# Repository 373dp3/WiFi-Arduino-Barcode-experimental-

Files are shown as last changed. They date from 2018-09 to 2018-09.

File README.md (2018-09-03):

# 概要
WiFiマイコン(ESP-WROOM-02)にバーコードリーダー、テンキー、1602液晶を組み合わせたミニマルなシンクライアントです。
生産工程などで大規模導入する場合、パソコン自体のコスト(初期、電気代等のランニングも無視できません。
WiFi Arduino Barcodeでは従来の1/10のコストでの生産工程進捗管理を目指します。

## システム構成(全体)
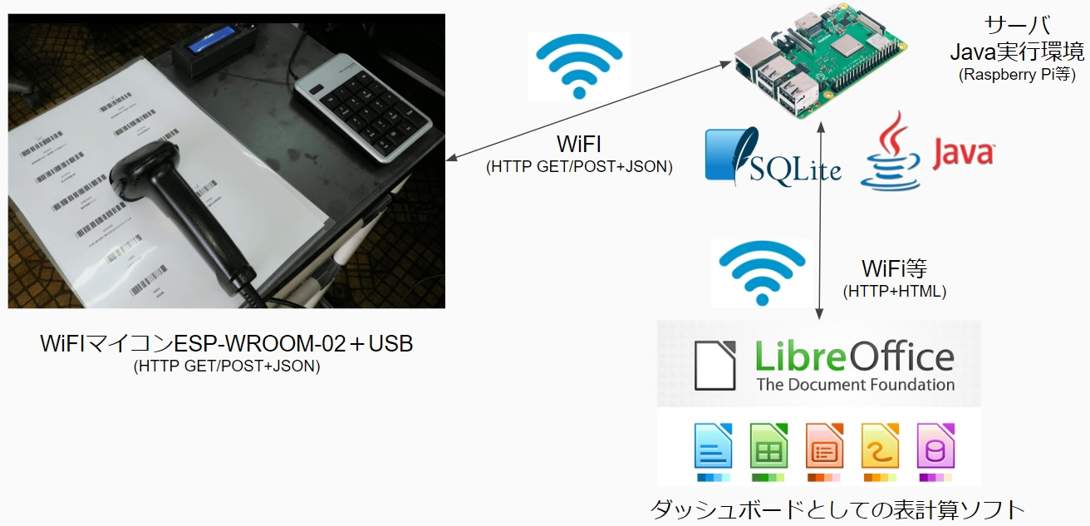
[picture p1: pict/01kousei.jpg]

<ul>
<li>WiFi Arduino Barcode(HTTP GET/POST & JSON)</li>
<li>ローカルサーバ / Javaを実行可能な環境 / (HTTP経由でのtable参照)</li>
<li>表示用表計算ソフト(LibreOffice等)</li>
</ul>

## ハードウェア構成(クライアント)
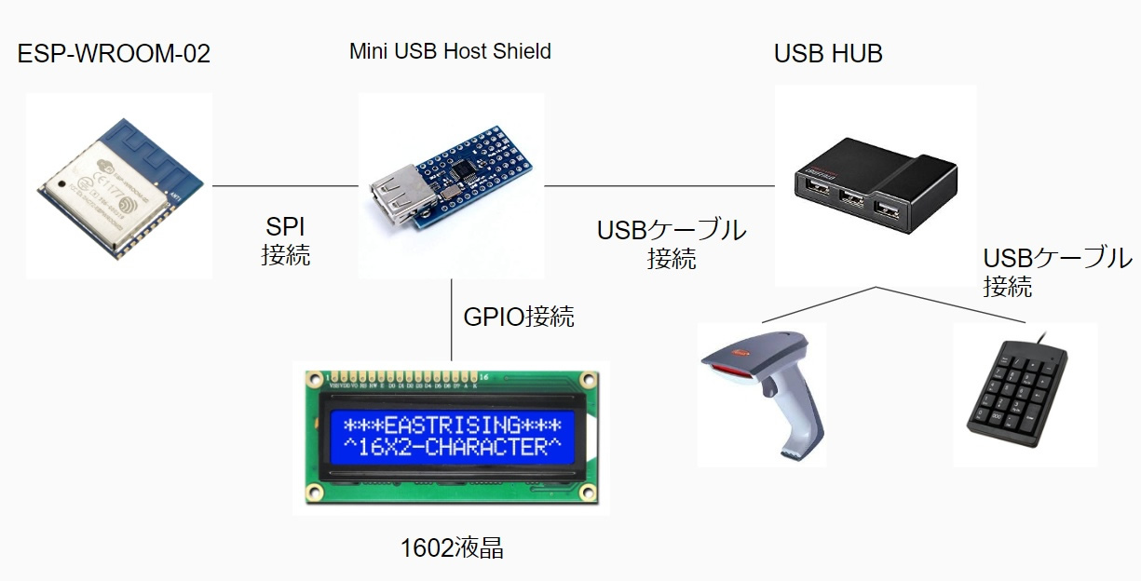
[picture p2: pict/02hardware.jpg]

<ul>
<li>ESP-WROOM-02</li>
<li>Mini USB Host Shield(SPI接続)</li>
<li>バーコードリーダー(USB接続)</li>
<li>テンキー(USB接続)</li>
<li>USBハブ</li>
<li>LCD1602(Mini USB Host Shield経由でのGPIO接続)</li>
</ul>

## フォルダ構成
<table>
  <tr>
    <td>client </td>
    <td>ESP-WROOM-02と<a href="https://amzn.to/2LSpzPm">Mini USB Host Shield</a>を用いたバーコードリーダー端末に関する情報
 </td>
  </tr>
  <tr>
    <td>client/eagle </td>
    <td>基板設計ソフト EAGLE用のファイル</td>
  </tr>
  <tr>
    <td>LocalBarcodeServer </td>
    <td>ローカルサーバ用ファイル一式 </td>
  </tr>
  <tr>
    <td>LocalBarcodeServer/binary </td>
    <td>実行に必要なファイルのみ </td>
  </tr>
</table>

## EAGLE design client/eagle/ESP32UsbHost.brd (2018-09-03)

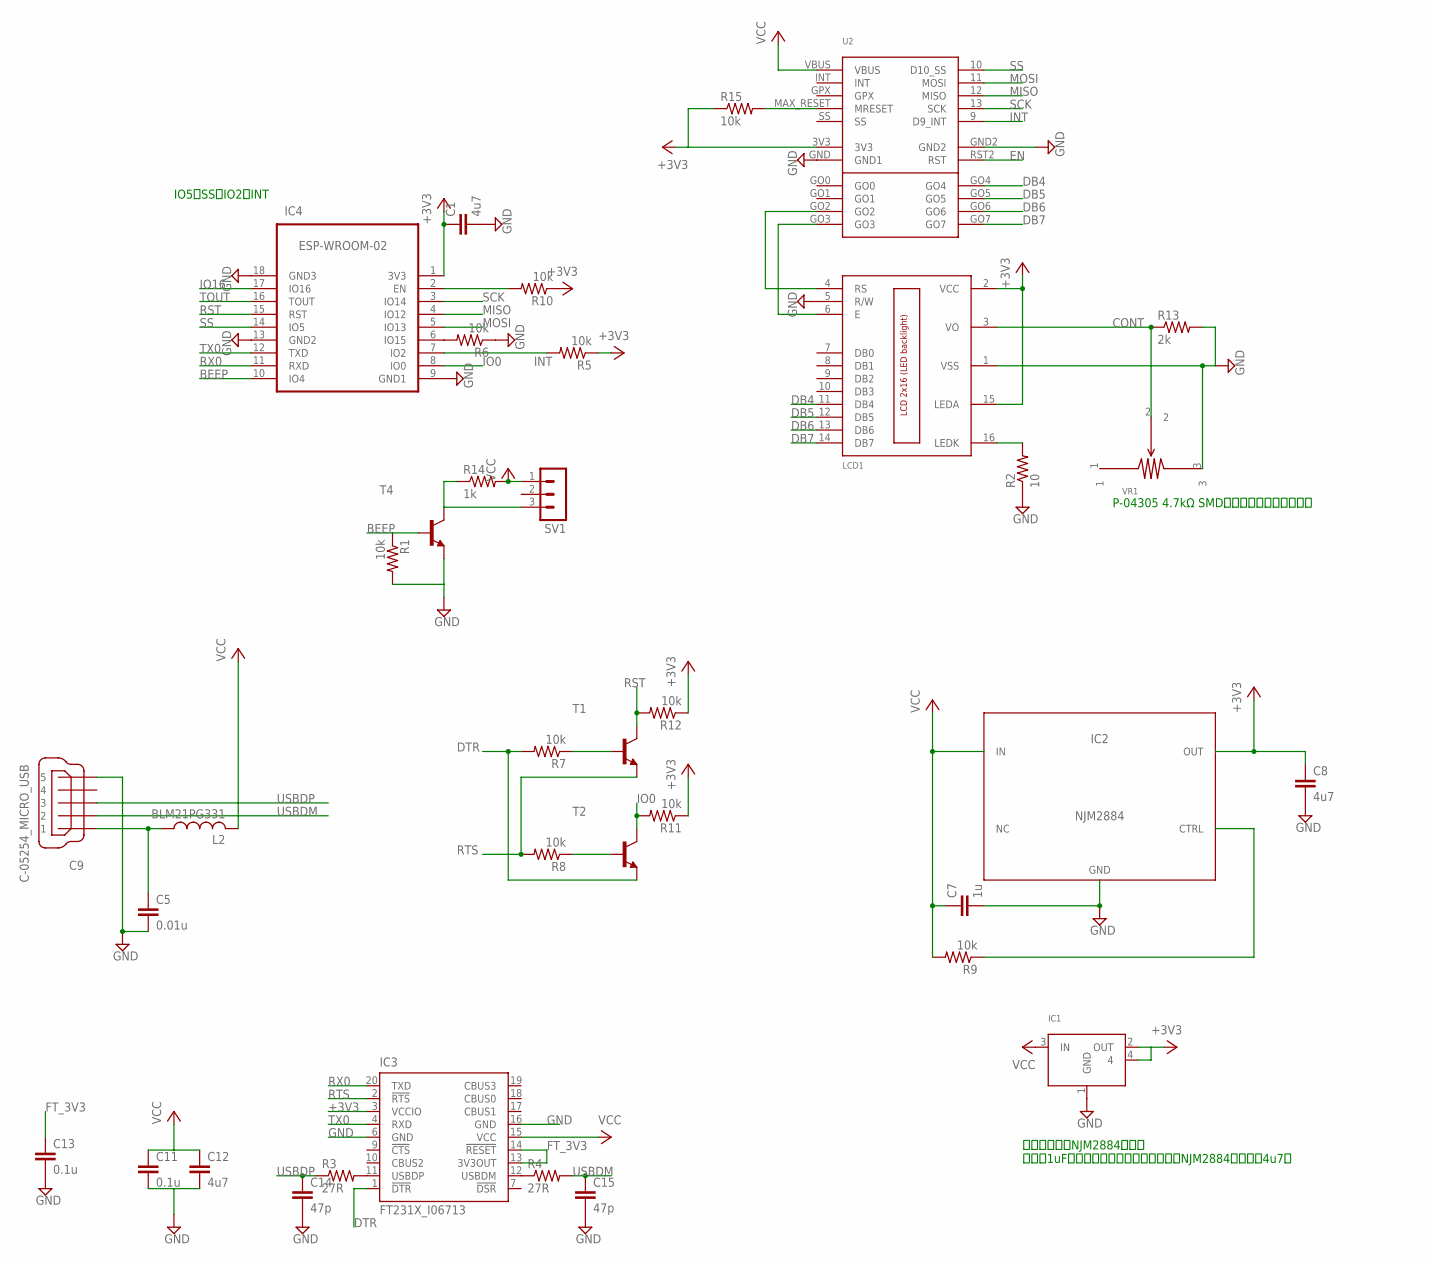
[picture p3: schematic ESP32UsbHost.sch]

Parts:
C1, C8, C12: 4u7; C0603
C5: 0.01u; C0603
C7: 1u; C0603
C9: C-05254_MICRO_USB
C11, C13: 0.1u; C0603
C14, C15: 47p; C0603
IC1: I-12635_ADP3338AKCZ; SOT223
IC2: NJM2884; SOT89-5
IC3: FT231X_I06713; SSOP20(2)
IC4: ESP-WROOM-02; FRONT-FACE_HANDSOLDER
L2: BLM21PG331; L2012C
LCD1: LCD_2X16CONN_ONLY; HY-1602F_2
R1, R5, R6, R7, R8, R9, R10, R11, R12, R15: 10k; R0603
R2: 10; R0603
R3, R4: 27R; R0603
R13: 2k; R0603
R14: 1k; R0603
SV1: MA03-1
T1, T2, T4: BC808-NPN-SOT23-BEC; SOT23-BEC
U2: USB_HOST_MINI
VR1: P-04305_PVZ3_VR_POTENTION_METER; VR_POTENTION_METER

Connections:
+3V3: C1.1, C8.1, IC1.2 (OUT), IC1.4, IC2.4 (OUT), IC3.3 (VCCIO), IC4.1 (3V3), LCD1.2 (VCC), LCD1.15 (LEDA), R5.1, R10.1, R11.1, R12.1, R15.1, U2.3V3
BEEP: IC4.10 (IO4), R1.1, T4.B
CONT: LCD1.3 (VO), R13.1, VR1.2
DB4: LCD1.11 (DB4), U2.GO4
DB5: LCD1.12 (DB5), U2.GO5
DB6: LCD1.13 (DB6), U2.GO6
DB7: LCD1.14 (DB7), U2.GO7
DTR: IC3.1 (!DTR), R7.2, T2.E
EN: U2.RST2 (RST)
FT_3V3: C13.1, IC3.13 (3V3OUT), IC3.14 (!RESET)
GND: C1.2, C5.2, C7.2, C8.2, C9.5, C11.2, C12.2, C13.2, C14.2, C15.2, IC1.1 (GND), IC2.2 (GND), IC3.6 (GND), IC3.16 (GND), IC4.9 (GND1), IC4.13 (GND2), IC4.18 (GND3), LCD1.1 (VSS), LCD1.5 (R/W), R1.2, R2.1, R6.1, R13.2, T4.E, U2.GND (GND1), U2.GND2, VR1.3
INT: IC4.7 (IO2), R5.2, U2.9 (D9_INT)
IO0: IC4.8 (IO0), R11.2, T2.C
IO16: IC4.17 (IO16)
MISO: IC4.4 (IO12), U2.12 (MISO)
MOSI: IC4.5 (IO13), U2.11 (MOSI)
unnamed: IC4.6 (IO15), R6.2
unnamed: LCD1.6 (E), U2.GO3
unnamed: LCD1.4 (RS), U2.GO2
unnamed: LCD1.16 (LEDK), R2.2
unnamed: IC3.12 (USBDM), R4.1
unnamed: IC3.11 (USBDP), R3.2
unnamed: IC4.2 (EN), R10.2
unnamed: R14.1, SV1.3, T4.C
unnamed: R15.2, U2.MAX_RESET (MRESET)
unnamed: R7.1, T1.B
unnamed: C5.1, C9.1, L2.1
unnamed: R8.1, T2.B
unnamed: IC2.1 (CTRL), R9.1
RST: IC4.15 (RST), R12.2, T1.C
RTS: IC3.2 (!RTS), R8.2, T1.E
RX0: IC3.20 (TXD), IC4.11 (RXD)
SCK: IC4.3 (IO14), U2.13 (SCK)
SS: IC4.14 (IO5), U2.10 (D10_SS)
TOUT: IC4.16 (TOUT)
TX0: IC3.4 (RXD), IC4.12 (TXD)
USBDM: C9.2, C15.1, R4.2
USBDP: C9.3, C14.1, R3.1
VCC: C7.1, C11.1, C12.1, IC1.3 (IN), IC2.5 (IN), IC3.15 (VCC), L2.2, R9.2, R14.2, SV1.1, U2.VBUS

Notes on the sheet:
コンデンサはNJM2884と共用 出力に1uF以上。温度安定性を考えれば、NJM2884と同じく4u7。
IO5がSS、IO2がINT
P-04305 4.7kΩ SMDトリマポテンショメータ

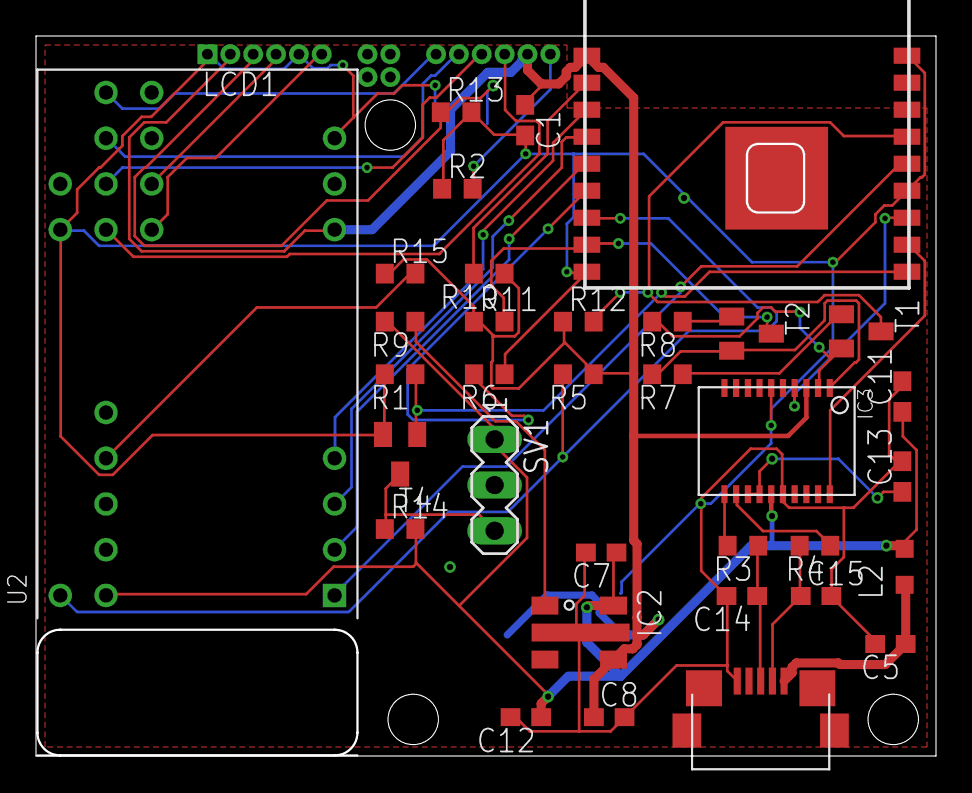
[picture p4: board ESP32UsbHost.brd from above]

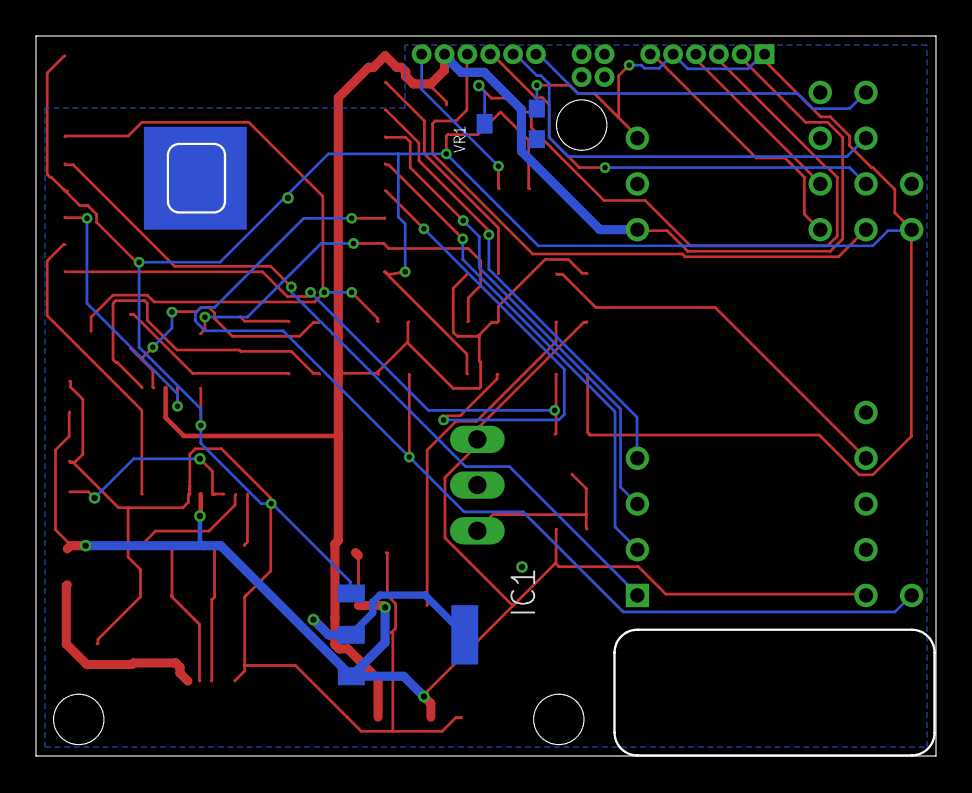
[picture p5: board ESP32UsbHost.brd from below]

Board: 2 copper layers, 50.0 x 40.0 mm, 37 parts (2 on the bottom side), 36 nets.

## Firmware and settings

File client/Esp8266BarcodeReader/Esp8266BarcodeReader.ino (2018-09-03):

/*
Name:		Esp8266BarcodeReader.ino
Created:	2018/03/06 8:42:33
Author:	min
*/

//#define DP3_ESP32

#include "Config.h"
#include "NetworkManager.h"
#include "TableViewManager.h"
#include "NormalOperationManager.h"
#include "CommonController.h"

#include <FS.h>

#include "HIDSelector.h"
#include "TxManager.h"
#include "FTDIAsync.h"
#include <cdcftdi.h>
#include <usbhub.h>
#include "LcdManager.h"

#ifdef dobogusinclude
#include <spi4teensy3.h>
#endif
#include <SPI.h>


NetworkManager net = NetworkManager();

StaticJsonBuffer<JSON_BUFFER_SIZE> JSONBuffer;



USB			Usb;
USBHub		Hub(&Usb);

// USB Hub and keyboard
USBHub     Hub2(&Usb);
HIDSelector    hid1(&Usb);
HIDSelector    hid2(&Usb);
HIDSelector    hid3(&Usb);
Max_LCD lcd(&Usb);
LcdManager scr(&lcd, BEEP_PIN);
HIDBoot<USB_HID_PROTOCOL_KEYBOARD>    HidKeyboard(&Usb);
CommonController *cc = NULL;
NormalOperationManager normOpMgr = NormalOperationManager();
TableViewWrapper * pTableOpMgr = NULL;

void updateConfig() {
	unsigned long timeout = millis() + 200;
	char* chBuf = (char*)malloc(JSON_POST_BUFFER_SIZE);
	char* chBuf2 = (char*)malloc(JSON_POST_BUFFER_SIZE);
	memset(chBuf, 0, JSON_POST_BUFFER_SIZE);
	memset(chBuf2, 0, JSON_POST_BUFFER_SIZE);
	int size = Serial.readBytesUntil(0x0d, chBuf, JSON_POST_BUFFER_SIZE);
	bool isReboot = false;
	if (size > 10) {
		memcpy(chBuf2, chBuf, JSON_POST_BUFFER_SIZE);
		JSONBuffer.clear();
		Serial.print("RECV:"); Serial.println(chBuf);
		JsonObject& parsed = JSONBuffer.parseObject(chBuf);
		if (parsed.success()) {
			if (parsed.containsKey("cmd")) {
				if (strcmp("format", parsed["cmd"].asString()) == 0) {
					Serial.println("Start SPIFFS format");
					SPIFFS.begin();
					SPIFFS.format();
					SPIFFS.end();
					Serial.println("format done.");
					Serial.println(F("{\"status\": 200, \"msg\": \"format done\"}"));
				}
				if (strcmp("ping", parsed["cmd"].asString()) == 0) {
					Serial.println(F("{\"status\": 200, \"msg\": \"pong\"}"));
				}
				if (strcmp("w", parsed["cmd"].asString()) == 0) {
					SPIFFS.begin();
					File file = SPIFFS.open(CONFIG_FILE, "w");
					if (file == NULL) {
						Serial.print("SPIFFS format");
						SPIFFS.format();
						Serial.println(" done.");
						file = SPIFFS.open(CONFIG_FILE, "w");
						if (file == NULL) {
							Serial.println(F("{\"status\": 500, \"msg\": \"Cannot format SPIFFS\"}"));
							return;
						}
					}
					file.print(chBuf2);
					file.close();

					Serial.println(F("{\"status\": 200, \"msg\": \"write done\"}"));
					isReboot = true;
				}
			}
		}
	}
	free(chBuf);
	free(chBuf2);
	if (isReboot) {
		delay(1000);
		ESP.reset();
	}
}


// the setup function runs once when you press reset or power the board
void setup() {
	Serial.begin(38400);
	Serial.setTimeout(200);
	Serial.println(F("Start"));


	if (Usb.Init() == -1)
		Serial.println(F("OSC did not start."));

	net.setupWiFi(&lcd);


	UsbDEBUGlvl = 0xff;
	Serial.println(F("USB host start"));
	hid1.init(); hid2.init(); hid3.init();

#ifndef DP3_ESP32
	//事前にロードしなくては音がでない場合がある為
	pinMode(BEEP_PWM_PIN, OUTPUT);
	analogWriteFreq(4000);
	analogWrite(BEEP_PWM_PIN, 128);
	delay(50);
	analogWrite(BEEP_PWM_PIN, 0);
	pinMode(BEEP_PWM_PIN, INPUT);
#endif


	//*/
	//入力フックの設定
	HIDSelector::setCommonController(&normOpMgr);

	lcd.clear();
	lcd.print("Connect USB ...");
	char chWait[] = { '-','\\', '|', '/' ,'-','\\','|','/' };
	while (1) {
		Usb.Task();
		if (Usb.getUsbTaskState() == USB_STATE_RUNNING) {
			lcd.clear();
			lcd.print("USB detected.");
			unsigned long limitMs = millis() + 3000;
			lcd.setCursor(0, 1);
			lcd.print("wait 3 sec.");
			for (int i = 0; i < 30; i++) {
				if (millis() > limitMs) { break; }
				delay(100);
				lcd.setCursor(12, 1);
				lcd.print(chWait[i % sizeof(chWait)]);
				Usb.Task();
			}
			break;
		}
		else {
			delay(500);
		}
	}

	//初期アクセス
	normOpMgr.post();
}



// the loop function runs over and over again until power down or reset
void loop() {
	Usb.Task();

	if (Serial.available() > 0) {
		updateConfig();
	}

	if (Usb.getUsbTaskState() != USB_STATE_RUNNING) { return; }

	scr.Task();
}

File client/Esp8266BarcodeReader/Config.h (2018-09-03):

// Config.h

#ifndef _CONFIG_h
#define _CONFIG_h

#if defined(ARDUINO) && ARDUINO >= 100
	#include "arduino.h"
#else
	#include "WProgram.h"
#endif

#ifdef DP3_ESP32
#include <WiFi.h>
#include <esp32-hal-ledc.h>
#else
//ESP8266だと仮定する。
#include <ESP8266WiFi.h>
#include <ESP8266HTTPClient.h>
//SS P5, INT P2
#endif

#include <ArduinoJson.h>
#include <max_LCD.h>


#ifdef DP3_ESP32
#define LCD_LED_PIN	(2)
#else
#define LCD_LED_PIN	(16)
#endif

//BEEP_PINは未接続の為、使用していないピンをダミーで
#define BEEP_PIN	(33)
#define CONTLAST_ANALOG_WRITE_PIN	(12)
#define LCD_LED_K_PIN	(14)

//ESP02 BEEP
#define BEEP_PWM_PIN	(4)
#define BEEP_PWM_FREQ	(4000)

#define JSON_BUFFER_SIZE	(5120)
extern StaticJsonBuffer<JSON_BUFFER_SIZE> JSONBuffer;

#define JSON_POST_BUFFER_SIZE	(512)

#endif

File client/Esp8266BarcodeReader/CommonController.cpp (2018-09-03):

// 
// 
// 

#include "CommonController.h"


void CommonController::beepCheck(JsonObject* pParsed) {
	if (pParsed == NULL) { return; }
	if (pParsed->containsKey("beep") == false) { return; }

	//以下、BEEPに関する情報が存在する場合の処理
	JsonObject& obj = (*pParsed)["beep"].asObject();

	int hz = 399;
	int value = 511;
	if (obj.containsKey("hz")) {
		hz = strtol(obj["hz"].asString(), 0, 10);
	}
	if (obj.containsKey("val")) {
		value = strtol(obj["val"].asString(), 0, 10);
	}
	char buf[512];
	obj.printTo(buf);
	Serial.print("beep: ");
	Serial.println(buf);

	//例外値対応
	if (value < 0) { value = 0; }
	if (value > 1024) { value = 1024; }
	if (hz < 100) { hz = 100; }
	if (hz > 10000) { hz = 10000; }

	//実際の駆動処理
#ifndef DP3_ESP32
	pinMode(BEEP_PWM_PIN, OUTPUT);
	analogWriteFreq(hz);
	analogWrite(BEEP_PWM_PIN, 0);

	JsonArray& ary = obj["ptn"].asArray();
	for (int i = 0; i < ary.size(); i++) {
		if ((i % 2) == 0) {
			analogWrite(BEEP_PWM_PIN, value);
		}
		else {
			analogWrite(BEEP_PWM_PIN, 0);
		}
		int sleepms = ary.get<int>(i);
		if (sleepms < 0) {
			sleepms = 0;
		}
		if (sleepms > 10000) {
			sleepms = 10000;
		}
		delay(sleepms);
	}
	analogWrite(BEEP_PWM_PIN, 0);
	pinMode(BEEP_PWM_PIN, INPUT);
#endif

}

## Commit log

2018-09-03 初期コミット
    [ESP32UsbHost.brd, ESP32UsbHost.sch, sheet_config.xlsx]
2018-09-03 起動関連
    [sheet_config.xlsx]
2018-09-03 README.mdの追加
2018-09-03 画像更新
2018-09-03 Revert "README.mdの追加"
    This reverts commit 0cf8ce130d72440b3f90f2d23c22faa8c3d970d5.
2018-09-03 README.mdの更新
2018-09-03 WiFiバーコード設定ツールの追加
2018-09-03 実行用バイナリの追加
